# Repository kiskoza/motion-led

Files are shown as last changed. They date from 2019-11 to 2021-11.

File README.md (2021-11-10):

# ESP8266 Motion Led

Turn on / off a led strip with a motion detector.

## Getting Started

### Prerequisites

You need to install `python` to use PlatformIO and `nodejs` + `yarn` to run Webpacker. Best way to do is install via asdf version manager.

```
asdf plugin add python
asdf plugin add nodejs
asdf plugin add yarn
asdf install
```

We need to install required packages

```
pip install -r requirements.txt
yarn install
```

And configure the environment variables

```
cp .env.example .env
nano .env
```

### Running

Then we could run a dev-server for the web

```
yarn run dev
```

... or build the whole project

```
yarn run build
```

## Running the tests

Currently there's no tests :(

Luckily we've got some code-style checkers:

```
yarn run lint
```

## Board

You can build the board based on the included KiCad project

## Deployment

Plug in the ESP module and:

```
yarn run deploy
```

## Built With

* [asdf-vm](https://asdf-vm.com/) - For easy install
* [KiCad EDA](https://kicad.org/) - For the hardware layout
* [PlatformIO](https://platformio.org/) - For the ESP module
* [Webpack](https://webpack.js.org/) - For the web interface

## Contributing

Please read [CONTRIBUTING.md](CONTRIBUTING.md) for details on our code of conduct, and the process for submitting pull requests to us.

## Versioning

We use [SemVer](http://semver.org/) for versioning. For the versions available, see the [tags on this repository](https://github.com/kiskoza/motion-led/tags).

## License

This project is licensed under the MIT License - see the [LICENSE.md](LICENSE.md) file for details

## Acknowledgments

* Hat tip to anyone whose code was used
* Inspiration
* etc

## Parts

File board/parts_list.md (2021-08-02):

# Parts list for the PCB

## Controller

ESP32 based Wemos D1 mini board

## ICs

- 3 x Transistors: IRLZ24N ([datasheet](https://www.hestore.hu/prod_getfile.php?id=3876))
- 1 x Voltage regulator: L7805CV ([datasheet](https://www.hestore.hu/prod_getfile.php?id=5181))
- 1 x PIR sensor: AM312 ([datasheet](https://www.image.micros.com.pl/_dane_techniczne_auto/cz%20am312.pdf))

## Analog parts

* Pin array:
  * 2 x ZL262-16SG ([datasheet](https://www.hestore.hu/prod_getfile.php?id=3271))
* Resistor:
  * 3 x 100 R
  * 3 x 1k
* Schottky diode:
  * 1 x 1N5817 ([datasheet](https://www.hestore.hu/prod_getfile.php?id=3963))
* Capacitor:
  * 1 x 10uF
  * 1 x 100nF
  * 1 x 330nF
* Connector:
  * PCGK2.1 ([link](https://www.hestore.hu/prod_10025579.html))
* External power supply:
  * KS 12V/1A ([link](https://www.hestore.hu/prod_10035814.html))

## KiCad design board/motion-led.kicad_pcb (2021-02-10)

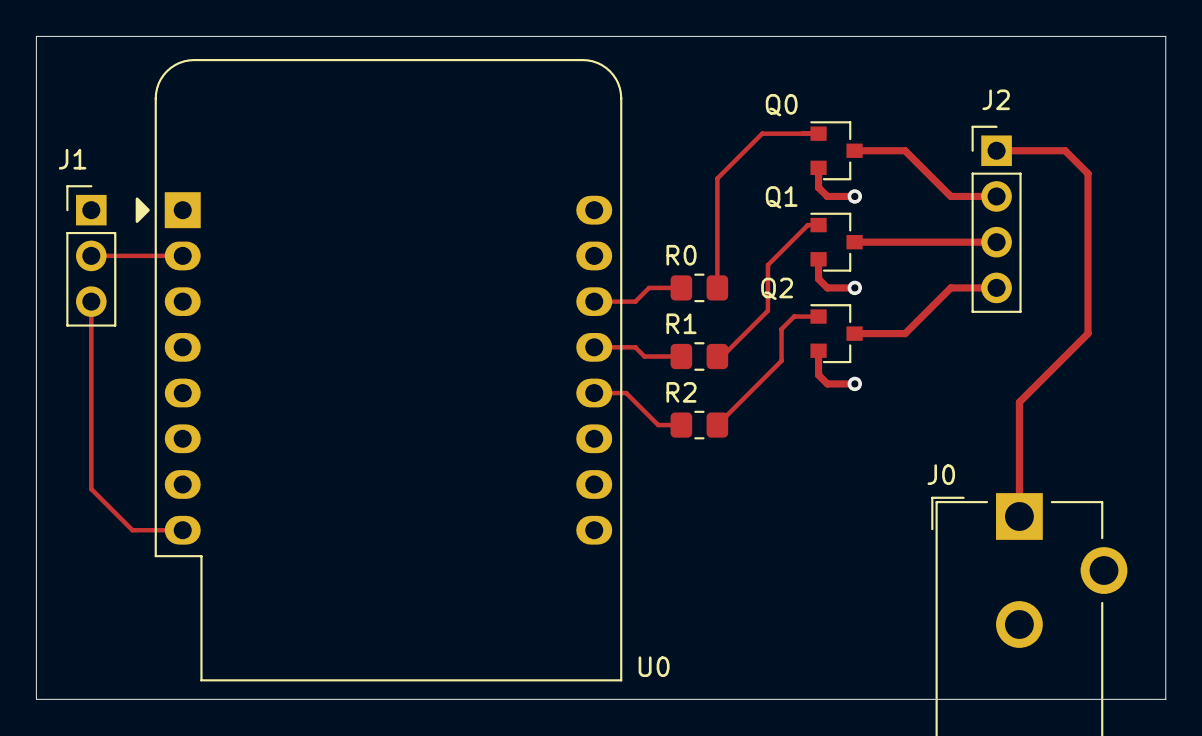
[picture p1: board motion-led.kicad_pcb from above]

Board: 2 copper layers, 62.7 x 36.8 mm, 10 parts (0 on the bottom side), 13 nets.

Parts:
J0: Barrel_Jack; BarrelJack_CUI_PJ-102AH_Horizontal
J1: AM312; PinHeader_1x03_P2.54mm_Vertical
J2: LED PINs; PinHeader_1x04_P2.54mm_Vertical
Q0, Q1, Q2: 2N7002; SOT-23
R0, R1, R2: 1; R_0805_2012Metric_Pad1.20x1.40mm_HandSolder
U0: WeMos_D1_mini; WEMOS_D1_mini_light

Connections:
GND: J0.2, J1.1, Q0.2, Q1.2, Q2.2, U0.10
unnamed: J0.1, J2.1
unnamed: J1.2, U0.2
unnamed: J1.3, U0.8
unnamed: J2.2, Q0.3
unnamed: J2.3, Q1.3
unnamed: J2.4, Q2.3
unnamed: Q0.1, R0.1
unnamed: Q1.1, R1.1
unnamed: Q2.1, R2.1
unnamed: R0.2, U0.14
unnamed: R1.2, U0.13
unnamed: R2.2, U0.12

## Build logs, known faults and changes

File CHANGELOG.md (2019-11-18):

# Changelog

All notable changes to this project will be documented in this file.

## [Unreleased]

## [v1.1.0] - 2019-11-16
### Added

- Compile all html files from the web folder
- Use define to ignore unused html files
- Move js to a separate endpoint

## [v1.0.0] - 2019-11-15
### Added

- Ability to run the project
- Generates an index response

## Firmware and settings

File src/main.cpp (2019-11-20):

#include <ESP8266WiFi.h>
#include <WiFiClient.h>
#include <ESP8266WebServer.h>
#include <FS.h>

#include "../dist/secrets.h"
#include "web.h"

const char* ssid = STASSID;
const char* password = STAPSK;

const int led = D4;
const int sensor = D3;

unsigned int timeout = 0;

void setup(void) {
  pinMode(led, OUTPUT);
  pinMode(sensor, INPUT);

  digitalWrite(led, 0);
  Serial.begin(115200);
  WiFi.mode(WIFI_STA);
  WiFi.begin(ssid, password);
  Serial.println("");

  // Wait for connection
  while (WiFi.status() != WL_CONNECTED) {
    delay(500);
    Serial.print(".");
  }
  Serial.println("");
  Serial.print("Connected to ");
  Serial.println(ssid);
  Serial.print("IP address: ");
  Serial.println(WiFi.localIP());

  SPIFFS.begin();

  server.on("/", handleRoot);
  server.on("/main.js", handleJS);

  server.onNotFound(handleNotFound);

  server.begin();
  Serial.println("HTTP server started");
}

void loop(void) {
  server.handleClient();

  int reading = analogRead(sensor);

  if (reading < 600) {
    if (timeout > 0) {
      timeout--;
    } else {
      digitalWrite(led, 1);
    }
    Serial.println("No motion detected!");
  } else {
    timeout = 100;
    digitalWrite(led, 0);
    Serial.println("Motion detected.");
  }

  delay(200);
}

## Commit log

2019-11-18 Small changes to sample
2019-11-18 Read PIR sensor with analog input, turn on builtin led on motion
2020-10-04 Add board schematic
    [motion-led.kicad_pcb, motion-led.sch]
2020-10-04 Update board schema
    [motion-led.sch]
2020-10-04 Assign footprints and check electrical rules
    [motion-led.sch]
2020-10-04 fix for PWR_FLAGs
    [motion-led.sch]
2020-10-04 Move led's 12V to the first pin
    [motion-led.sch]
2021-02-10 PCB layout for the board
    [motion-led.kicad_pcb, motion-led.sch]
2021-02-10 Finalize PCB
    [motion-led.kicad_pcb]
2021-07-24 Changed placing for a more easy-to-read schematic Fixed gate resisor values to match microcontroller output current limitations Added discharge resistor to gate drive
    [motion-led.sch]
2021-07-24 Dummy commit, same as above
    [motion-led.sch]
2021-07-24 Added schottky diode for reverse polarity protection Added frames and names to different parts of the schematic
    [motion-led.sch]
2021-07-24 Added parts list to the PCB design
2021-07-24 Fixed Gate resistors to maintain 33mA consumption on GPIOs
    [motion-led.sch]
2021-07-24 Fixed transistor types to mach the specifications
    [motion-led.sch]
2021-07-26 Fixed power supply, now 5V is connected to the ESP and the motion sensor Fixed badly placed flags
    [motion-led.sch]
2021-07-26 Fixed parts_list.md to mach current PCB design
2021-08-02 Fix voltage values on schematic
    [motion-led.sch]
2021-08-02 Add dataseet for AM312 PIR sensor
2021-08-02 Update part list and schematics
    [motion-led.sch]
2021-09-17 Added efficient, switching regulator based power supply
    [motion-led.sch]
2021-09-17 Added 12V flag to the new pwr supply
    [motion-led.sch]
2021-09-20 Added low pass filter to ESP power pin
    [motion-led.sch]
2021-11-10 Update README.md
    https://forum.kicad.info/t/warning-avoid-all-links-to-kicad-pcb-org-use-kicad-org/31521
